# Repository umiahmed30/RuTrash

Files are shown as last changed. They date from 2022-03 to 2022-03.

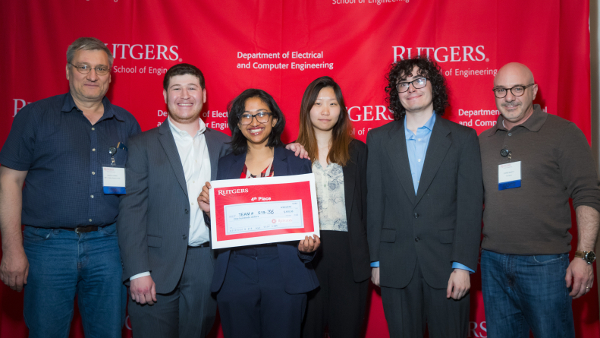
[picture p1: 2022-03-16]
4th-Place-2019_04_24_0681_RU_SOE_Capstone-600x338.jpg

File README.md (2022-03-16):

# RU Recycle
Fourth place winner of the Rutgers Capstone Expo 2019. Refer to the documents section for report, demo video, and poster.

Abstract:

America accumulates more than 254 million tons of trash annually, but recycles only 34.5% of its total municipal waste. Although most are aware of the consequences of pollution and landfills, many individuals fail to recycle accurately due to lack of access or inconvenience. Our team proposes a solution to this issue with a self sorting trash can. This device will use computer vision and various sensors to categorize a disposed item and send it to the appropriate bin using a conveyor belt mechanism. We will finetune the Resnet-50 neural network architecture with thousands of images of waste to categorize its findings into: paper, plastic, metal, glass, and trash. We will use a Raspberry Pi 3 B+ in conjunction with an Arduino Pro Micro to control the conveyor belt system. With our project, we aim to streamline the process of recycling with efficiency and accuracy.

Acknowledgements: 

Training Dataset obtained from Trashnet: https://github.com/garythung/trashnet

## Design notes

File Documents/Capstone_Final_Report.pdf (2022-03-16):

# RU Recycle: A Smart Self-Sorting Trash Can Using

# Deep Neural Network

Steven Coulter, Umama Amhed, Yiwen Zhou, Jake Rodin, Professor Sheng Wei

May 8, 2019

## Contents

1 Introduction | 4
2 methods | 6
3 Cost and Sustainability Analysis | 16
4 Conclusion | 18
5 Apendix | 18

6 Works Cited | 26

## 1 Introduction

In the US we produce a significant amount of waste but only recycle a small amount of it. According the

EPA, “In 2013, Americans generated about 254 million tons of trash and recycled and composted about

87 million tons of this material, equivalent to a 34.3 percent recycling rate. On average, we recycled and

composted 1.51 pounds of our individual waste generation of 4.40 pounds per person per day,” (EPA, 2016).

That 254 million tons of trash can be sorted by type of waste, shown in this plot.

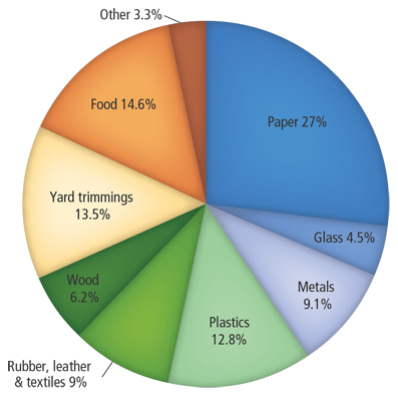
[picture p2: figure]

Figure 1: Percentage of Types of Waste Produced in 2013 (EPA,2016)

It clearly illustrates that the US disproportionally disposes of a lot of recyclable material as garbage. In

total 53.4 percent of our waste in 2013 was recyclable but we only recycled 34.3 percent of it. This disparity

is due to many factors, according to a 2016 article in the Huffington Post, The three major responses,

as illustrated in the plot below, on why people do not recycle in order from most to least common are:

people seeing recycling is inconvenient, it takes too much time and forgetfulness. These excuses have greatly

hindered our efforts to effectively recycle.

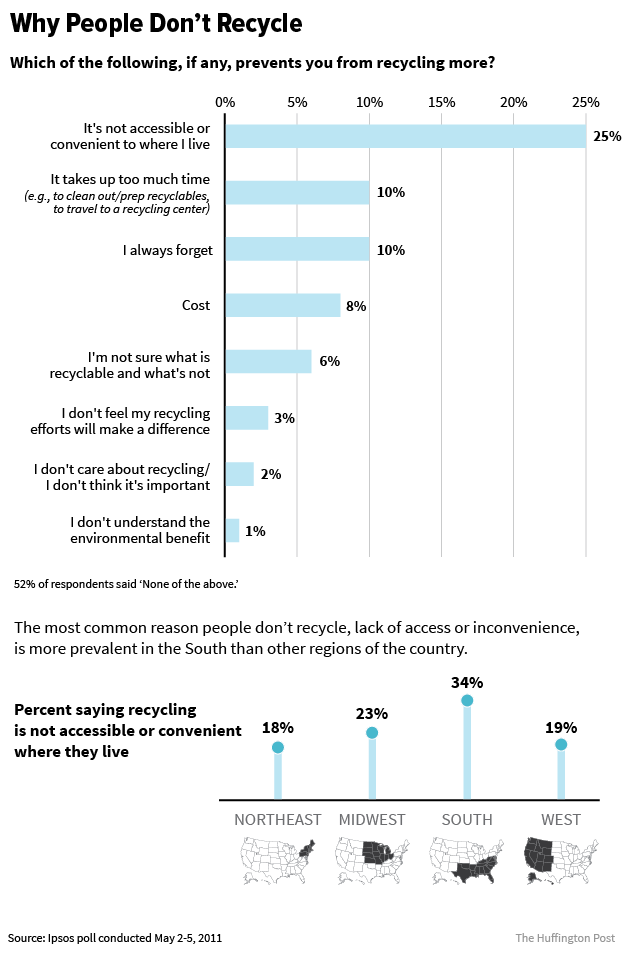
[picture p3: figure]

Figure 2: Responses to Why People Don’t Recycle (Schumaker, 2016)

In response to these problems of inconvenience, we created a self-sorting trash can. This solution would

make it easy for the user by decreasing time and eliminating the ”thought” that goes to sorting waste, as well

as cut down on the amount of menial labor required at recycling plants. This device will use deep learning

and various sensors to categorize the disposed item and send it to the appropriate bin using a conveyor belt

mechanism. The neural network we fine tuned uses thousands of images of waste to categorize its findings

into paper, plastic, metal, glass, and trash. We will use a Raspberry Pi 3 B+ in conjunction with an Arduino

Pro Micro to control a conveyor belt system. With our project, we aim to streamline the process of recycling

while maximizing efficiency and accuracy to a degree that other similar products do not.

An example of a similar product would be CleanRobotics’ TrashBot, which “utilizes a variety of sensors,

robotics and artificial intelligence (AI) in order to detect what a piece of waste is, classify it as recyclable or

not, then separate the item into the correct receptacle,” (Greenwalt, 2017). Our project intends to take it

a step further and sort the waste into five separate categories of paper, plastic, metal, glass, and trash. By

having all the waste sorted before it reaches the recycling plant, our project will help decrease the amount of

time, labor, and money expended by either users at home or recycling plants. This project will streamline

the process of recycling while also decreasing the amount of time money and effort needed to recycle.

## 2 methods

As mentioned before, our goal was to create a device that uses deep learning and various sensors to categorize

an item and send it to the appropriate bin through a conveyor belt mechanism. We used a variety of methods

in order to successfully implement our design. We tackled this project from two engineering aspects: hardware

and software.

### 2.1 Flowchart

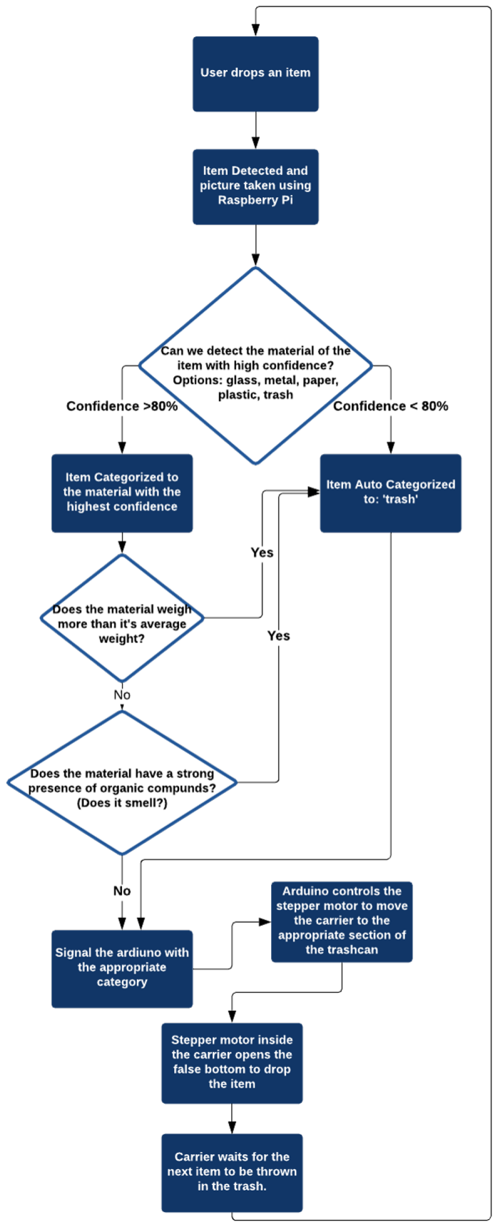
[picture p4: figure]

Figure 3: a flowchart detailing the project

### 2.2 Methods Used

### 2.2.1 Hardware

Before we started this project, we had to familiarize ourselves with some of the technologies we plan to use.

From a hardware perspective, we needed to know how to use stepper motors, limit switches, and general pcb

design. Some other skills that are required is a basic knowledge of soldering, constructing objects with power

tools, and operating a 3D printer, which allows for faster acquisition of parts at a low cost. Experience with

serial connections and C allowed for better use of the Arduino and bridging to the PI. Understanding and

use of a laser cutter was also a necessary skill in order to produce the parts necessary for the projects.

### 2.2.2 Software

From the software side, the following were our design goals:

1. Use an appropriate machine learning architecture to finetune with our dataset.
2. Find a dataset to train given our recycling categories.
3. Pick a programming language that allows for easy interface with the Raspberry Pi and allows for easy

use of neural network programming.

In addition, we had to be well acquainted with unix operating systems, crontab operations, and shell scripting

in order to save power and run our system efficiently.

### 2.3 Design Implementation and chalanges

### 2.3.1 Hardware

### 2.3.1.1 Design

The device operates on the principle of linear control through a stepper - belt mechanism and control through

an Arduino and Raspberry Pi mechanism. If the Raspberry Pi sends data to the Arduino, then the Arduino

will respond by controlling the steppers to move over the top of the correct trashcan segment and have a

servo drop the trash. The stepper will move back and forth to shake any excess trash off the platform. The platform will then reset and the carrier will move back to the home position. This creates a feedback loop

that is illustrated in the above flowchart.

### 2.3.1.2 Challenges

One of the largest challenges that we have encountered from the hardware perspective is the design constraint

of the physical trash can. As it stands we have currently solved this by merging two existing trash cans;

however ordering the chosen cans has proven difficult. Due to time constraints, we are forgoing creation of

a specialized control unit that is capable of both control of the can and image analysis, such a control unit

would be more effective in a large scale project however in the interest of the prototype, Thus in favor of both

time and money, we have chosen to use a two board system, consisting of a Raspberry Pi and an Arduino.

Overall we have not run into many regulatory issues, other than recycling standards and sorting codes.

However, we expect the nuances of recycling code impede us in the future. Additionally, conventional trash

cans available in stores are not large enough to house five types of trash in a realistic situation. Solution:

merge two trash cans together to give more room to each compartment. The synchronization of the stepper

motors caused a big challenge in the hardware side. In order to make them turn in sync, they had to be

driven from the same Arduino pin. This caused issues, as one stepper driver originally did not use as much

current as the other, causing issues in the feed torque and forcing the carrier to have a torque along the rods.

Solution: tune the current output of the steppers using a multimeter.

### 2.3.2 Software

### 2.3.2.1 Design

From the software side, we wrote two python scripts to train and test our machine learning architecture and

one final script to detect objects with machine learning and the sensors combine. Once an item is thrown into

our device, we take a picture using Raspberry Pi camera and calculate the sorting category using the test

code. If we can not determine a suitable category with at least 70% confidence, we will auto assign the item

to the ‘trash’ category. Due to the fact that a wide variety of items can be thrown in trash, sometimes it can

be challenging even for humans to decide if an item can be recycled or not. To avoid cross contamination,

we do not want to throw things into one of the recycling categories unless we are absolutely confident of the

resulting category. Furthermore, we had to find a database of images of trash that suited our needs. From

our research online, we found the Trashnet, which was the most complete open source database that included

variety of pictures from all our categories. We obtained permission from the creators before continuing on with our project. We had to modified the database a little to include cardboard into paper category. “The

pictures were taken by placing the object on a white poster board and using sunlight and/or room lighting.

The pictures have been resized down to 512 x 384, which can be changed in data/constants.py (resizing them

involves going through step 1 in usage). The devices used were Apple iPhone 7 Plus, Apple iPhone 5S, and

Apple iPhone SE” (Thung, 2017).

### 2.3.2.2 Code Layout

In the following paragraphs, we will describe how we fine-tune our architecture to detect our recycling

categories. We have chosen to work with ResNet50. While there are a lot of CNNs out there, a problem

with directly mapped networks was that the deeper the networks were, the accuracy saturated and degraded

more rapidly. ResNet uses network layers to fit a desired underlying mapping. It is easy for a residual block

to learn an identity function, thus it allows us to add more and more layers to our training blocks without

degrading quality of increasing training error (Jay, 2018). ResNet also uses a lot of the same convolutions so

the dimensions between layers stay consistent. ResNet50 is a 50-layer Residual Network but there are other

variants like ResNet101 and ResNet152 also. Below is an example of a residual block of ResNet: Below we

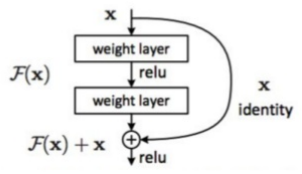
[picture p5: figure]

Figure 4: Residual block (Jay,2018)

will highlight the step-by-step process to fine tuning:

1. Preprocessing: keras includes a built-in image data generator which generates batches of image data

with real time data augmentation looped over in batches. This is executed to suppress unwanted dis-

tortions or enhance some image features important for the next level. We use the flow from directory()

function to specify our training directory. We set our class mode to categorical to categorize the 5

classes, set shuffle to true to randomize our images, and set our batch size to 16. Batch size defines the number of samples propagated through the network: typically networks train faster in mini batches so

we have chosen the value to be 16.

2. Fine-tuning Layers: After loading up ResNet 50, we have chosen to truncate the last layer with

model.layers.pop(). Since we are only classifying 5 categories, we are replacing the layer with our own

softmax layer so instead of the 1000 categories of imagenet, the new layer will only look at 5. From

research we have found that it is common practice to freeze the previous layers of the pre-trained

network. The initial layers extract universal features like curves and edges that are still relevant to the

new classes, so we have chosen to not modify them. Another parameter to define here is the learning

rate: it is simply the rate at which the network abandons old weights for new ones. we chose a very

small learning rate of 0.0001, since the pre-trained weights are already pretty good, we don’t want to

distort them too much.

3. Model Fitting: we use the keras function fit generator() to start the fine-tuning process. The number

of training steps is specified to be training samples/batch size. We use a total of 2500 pictures to train

our 5 classes and 30 images per category to validate. The term epoch refers to the number of times the

entire dataset is passed forward and backward through the neural network. As the number of epoch

increases, the number of times the weight changes increases as well. Now this could be a good thing

and a bad thing: the good news is more epoch will result in underfitting whereas too many epochs

can cause overfitting. The term overfitting means a network will be so good at recognizing your own

dataset that it won’t be able to recognize new images with slightly different parameters. Underfitting

will give us a network that is too generalized to accurately recognize any images. To solve this issue

we will use a method called early stopping.

Figure 5: Early Stopping function

Setting the patience to 10, we have basically setup a checkpoint to test if the loss has improved in the last

10 epoch. We set up save best only to true to save the best model after each checkpoint.

### 2.3.2.3 Challenges

Due to the fact that a wide variety of items can be thrown in trash, it can be challenging even for humans

to decide if an item can be recycled or not. For example, containers with food/liquid still inside should

not be recycled in order to avoid cross contamination. Solution: Add weight sensor and Volatile Organic

Compound (VOC) sensor to the carrier. These sensors will help determine if food particle/excess liquid is

still inside a container. For example, if a plastic bottle is thrown into our device with liquid still inside, we

would be able to use the weight sensor to determine that the object weighs more than an average plastic

bottle, hence it belongs to trash. Additionally, if a greasy napkin is thrown into the device, we would be

able to use the VOC sensor to detect the food particles and send the item to trash.

### 2.4 Tools used:

- Android Studio
- Oracle VM Virtual Machine on our windows 10 to use Ubuntu (64 bit)
- Python 2.7
- ResNet50
- trashnet
- Laser Cutter
- arduino IDE
- EasyTerm.

### 2.5 Limitations

### 2.5.1 Hardware

A Raspberry Pi is not quite fast enough for simultaneous use of the neural network and drive stepper motors.

Secondarily, we have run into the issue of availability of some parts, namely the trashcans and the steel rods.

However most of the technology we need is consumer grade technology and off the shelf CNC hardware, so

it was easily implimented.

### 2.5.2 Software

We only have about 2500 images from trashnet, which is enough for now but will not be enough if this device

was used at a large scale. So what we plan to do is continue to grow the database by uploading the picture of any trash that we come across in our device, then once we have x amount of pictures, we will retrain our

architecture.

### 2.6 Use of Standards

- IEEE 802.11 - Wifi, our project will employ wifi in order to communicate data back to our main servers.
- RS-232 - in order to enable communication between the Raspberry Pi and Arduino use of serial com-

munication is required.

- RESNET50 - See Above paragraph on use of neural net
- Python 2.7 - Used to facilitate resnet50
- Tensorflow: Used to facilitate resnet50
- IEEE 1666-2005 - C standard library package, useful for arduino, 2005 version still relevant though

newer versions available

- IEEE Standard 1003.1 - Bash standard, useful to limit power consumption on the pi because running

the whole python script (having the entire neural network in ram at all times) would consume a lot of

power.

### 2.7 Experiment/Product results

### 2.7.1 Hardware

The system functioned as intended. The hardware was able to move to the correct due to application of

method of successive approximations. Below are some pictures of the functional hardware.

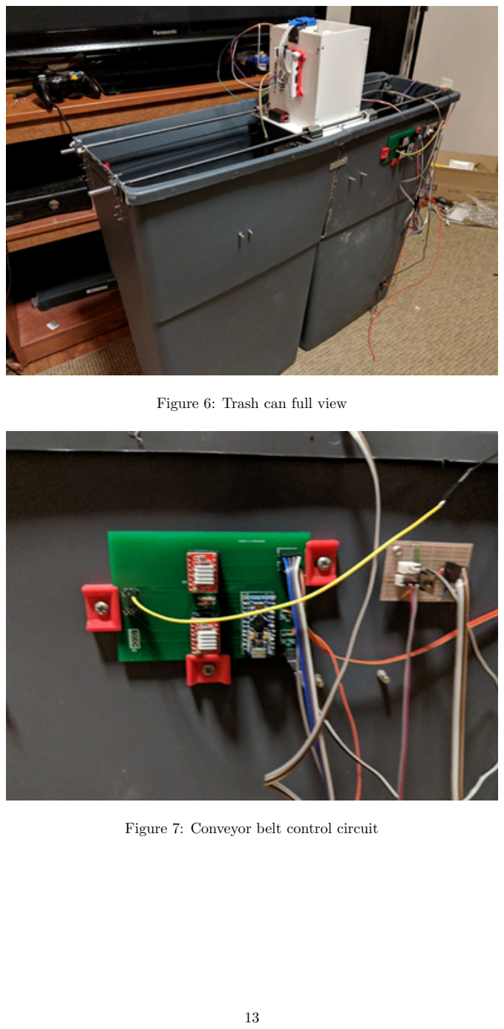
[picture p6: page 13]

Figure 6: Trash can full view

Figure 7: Conveyor belt control circuit

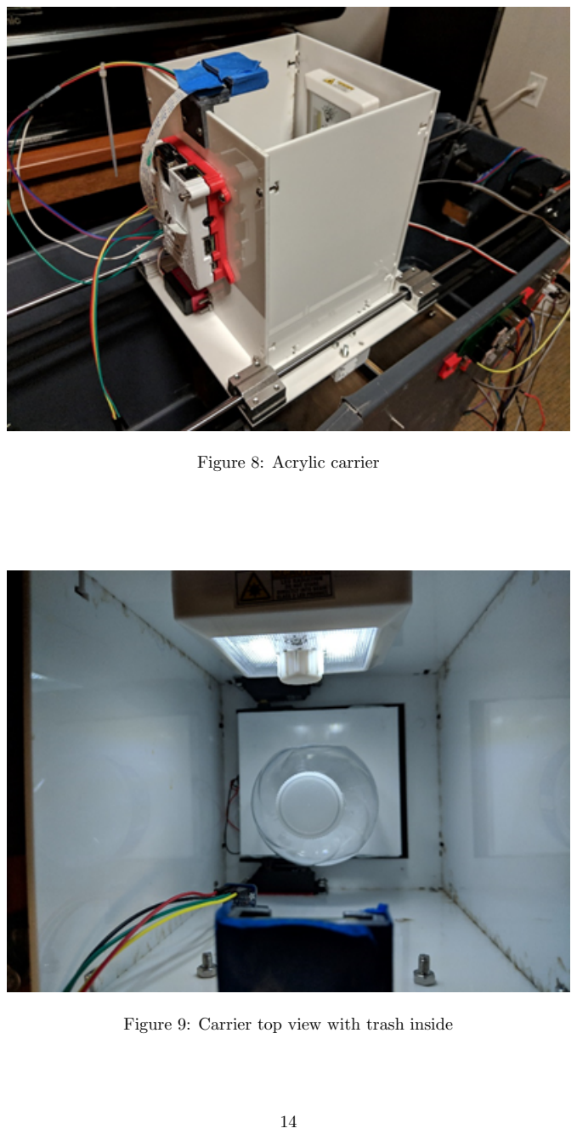
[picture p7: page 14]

Figure 8: Acrylic carrier

Figure 9: Carrier top view with trash inside

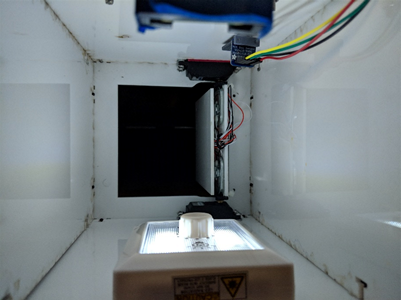
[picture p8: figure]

Figure 10: Carrier top view with false bottom open

### 2.7.2 Software

After training against the trashnet, I used 30 pictures of each category using the Raspberry Pi camera to

test my prediction algorithm. I used sklearn to collect the accuracy, precision, recall, f-score to create my

classification report. I also collected the accuracy of my prediction algorithm as seen below:

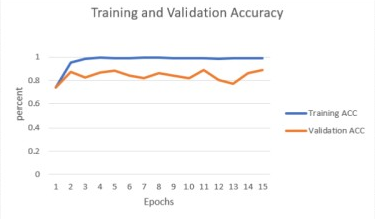
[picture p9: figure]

Figure 11: Training and Validation Accuracy vs the number of epochs

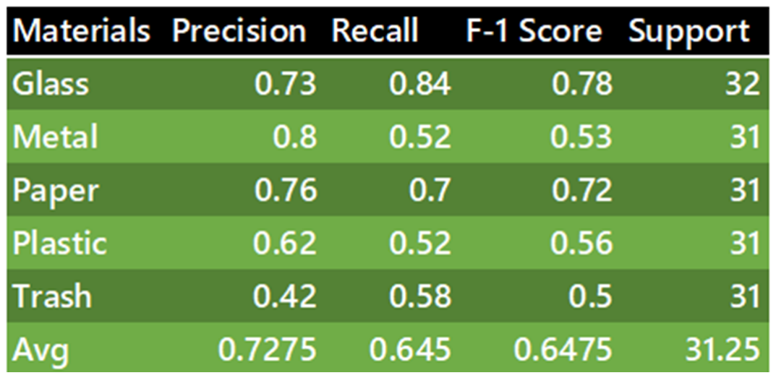
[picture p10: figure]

Figure 12: Classification Report

As observed, glass, metal and paper was accurately validated over 70% of the times. Plastic was

validated 62% of the time. Trash generated the worst result with 42% precision. The reason for precision

of trash being significantly lower than the others is because the category itself is very diverse. Many things

can be categorized as trash: some that may seem like they belong in one of the other categories at first

glance. Therefore, we used the VOC sensor and weight sensor to decrease our errors. With more pictures

of disposable items and a processing unit and camera more powerful than those provided by the Raspberry

Pi, we would be able to increase our accuracy even more.

## 3 Cost and Sustainability Analysis

### 3.1 Economics (cost) impact

Our prototype costs $277.96. However, the price can be greatly reduced if we were to move our product into

mass production. Buying items, such as metal rods, kevlar belts, and cables, in bulk would greatly reduce

the cost for each individual bin. Currently, we are modifying premade trash cans to our specific design;

although, if we were to employ a factory to make bins with our specific dimensions in large quantities, it

would again greatly reduce the price and time to produce our product. The majority of costs for our electrical

components can also be cut if we were to mass produce specific components for our trash can. This product

is also energy efficient. When the trash can is not sorting, it turns off, so it does not draw power when it

is not needed. According to a study from 2001 released by CalRecycle (formerly the California Integrated

Waste Management Board), recycling one ton of waste would be equal to a pay increase of “$101 in salaries

and wages, produce $275 more in goods and services, and generate $135 more in sales than disposing of it in a landfill” (Morrigan, 32). Using these numbers, if half of the recyclables and compostables from the west

coast (California, Oregon, and Washington) reported in this study were recycled, then the result would be

“almost a $1.6 billion increase in additional salaries and wages, $818 million increase in additional goods and

services produced, and $309 million increase in additional sales” (Morrigan, 32). These numbers would also

translate to increased revenue for each state, especially through income, property, and sales taxes (Morrigan,

32). Of course, if we calculated this on a national number, the numbers would be even bigger. In fact, the

EPA (Environmental Protection Agency) has done these calculations in an update to the national Recycling

Economic Information (REI) Study in 2016. The study found that a single year of recycling in the United

States accounted for 757,000 jobs, $36.6 billion in wages, and $6.7 billion in tax revenues (“Recycling Basics”,

2018).

### 3.2 Environmental impact of the product

Our autonomous sorting trash should provide a positive impact to the environment. The average US citizen

discards 7.5 pounds of solid waste a day (“Frequently Asked Questions: Benefits of Recycling”, 2019). By

removing recyclables from the solid waste stream, we save a lot of space in landfills, preventing them from

overflowing too quickly. Recycling also slows down our consumption of natural resources like wood and

water, prevent pollution because we are reducing the need to collect raw materials, and save the energy

needed to manufacture new products (“Benefits of Recycling,” 2019). For example, recycled aluminum saves

95% production energy, recycled steel 60%, recycled newspapers 40%, recycled plastics 70%, and recycled

glass 40% (“Benefits of Recycling,” 2019). In 2010, to meet the growing paper consumption demands, 80%

more wood would need to be harvested in comparison to only 20% more wood needed if people were actively

recycling paper (“Benefits of Recycling,” 2019). Recycling reduces greenhouse gas emissions too (“National

Overview: Facts and Figures on Materials, Wastes and Recycling”, 2018).

### 3.3 Social impact of the product

Our product will make recycling less labor intensive and more convenient for the average consumer. It will

cut down the time and energy needed for everybody to recycle and the need for manual recycling in single

stream recycling facilities. It also reduces the need for landfills, which would make towns prettier and less

smelly on days where the wind blows in the wrong direction.

## 4 Conclusion

Our goal for this project was to make the process of recycling more accurate and efficient at the bin level.

We were able to do so by creating a device that sorts and disposes of items thrown with high accuracy. We

fine tuned the Resnet-50 neural network architecture with thousands of images of waste to categorize its

findings into: paper, plastic, metal, glass, and trash. We used a Raspberry Pi 3 B+ in conjunction with an

Arduino Pro Micro to control the conveyor belt system. We were able to achieve a precision score of 72%

on average among the 5 categories. Trash being a complex category, achieved the lowest precision score, so

we improved our results by adding a VOC sensor and a weight sensor to detect leftover food in the disposed

item. In the future, we would like to use a more powerful processing unit than Raspberry pi to decrease

operation time at the software level. We want to collect more pictures of disposable items to improve our

fine tuning architecture. From the hardware side, we would like to build a bigger acrylic carrier to allow for

larger items to be disposed. Additionally, we plan to experimentally determine the location of the bins and

rotation of the belts to eliminate any possibility of dropping an item in the wrong section of the trash can.

## 5 Apendix

Attached below is our code for the project:

### 5.1 predict.py

the live runnable for our code demo On the raspberry Pi

import json , os , re , sys
import numpy as np
from keras import backend as K
from keras.models import load model from keras. preprocessing import image from picamera import PiCamera
from time import sleep
from PIL import Image
import serial
import board
import busio
import adafruit sgp30
import time

#I n i t i a t e weight sensor

EMULATE HX711 =False
if not EMULATE HX711 :

import RPi.GPIO as GPIO
from hx711 import HX711
else:
from emulated hx711 import HX711

def cleanAndExit ():
print ("Cleaning...")

if not EMULATE HX711 :
GPIO.cleanup ()

print ("Bye!")
sys.exit ()

hx = HX711 (5, 6)

if | n a m e | == ’ | m a i n | ’:
model path = sys.argv [1]

print (’Loading serial’)
for x in range(10):
name = ’/dev/ttyACM’ + str(x)
| try:
ser = serial.Serial(name)
except:
continue

print(ser.name)

print(’Loading model:’, model path ) model = load model ( model path ) image2 = ’image2.jpg’
| run= ’y’

voc = True
weight sensor = True

# Setup i2c

print(’Setting up i2c...’) try:
thres smell = 0
min smell = 0
max smell = 0
smell = []
i2c = busio.I2C(board.SCL , board.SDA , frequency =100000) sgp30 = adafruit sgp30 . Adafruit SGP30 (i2c)
sgp30. iaq init ()
sgp30. set iaq baseline (0x8973 , 0x8aae)
for i in range(40):
print("eCO2 = %d ppm \t TVOC = %d ppb" % (sgp30.eCO2 , sgp30.TVOC))

sleep (1)
except:
print ("VOC failed")

voc = False

# Setup weight sensor

print(’Setting up weight sensor...’) try:
hx. set reading format ("MSB", "MSB") hx. set reference unit (4.09) hx.reset ()
hx.tare (50)
offset prev = hx.tare (50) except:
print ("weight sensor failed") weight sensor = False
print ("Place object now...")

while(run ==’y’):
thres smell = 0
camera = PiCamera ()
camera. start preview ()
sleep (10)
camera.capture(image2)
camera. stop preview ()

if voc:
smell = []
for i in range(20):
eCO2 = sgp30.eCO2
TVOC = sgp30.TVOC
print("eCO2 = %d ppm \t TVOC = %d ppb" % (eCO2 , TVOC))

smell.append(TVOC)
sleep (0.25)
smell = np.array(smell)
b = smell[::−1]
max smell = len(b) − np.argmax(b) − 1 if ( max smell == 0 ):
thres smell = 0
min smell = max smell
else:
min smell = np.argmin(smell [0: max smell ])
thres smell = smell[ max smell ] − smell[ min smell ] print("max", smell[ max smell ], "min", smell[ min smell ])

imageCrop = Image.open(image2)
cropped = imageCrop .crop ((570 ,105 ,1365 ,830))
save = cropped.save(’imageC.jpg’)
img2 = image. load img (’imageC.jpg’, target size =(224 , 224)) y = image. img to array (img2)

hx. set offset A ( offset prev )
y = np. expand dims (y, axis =0)
preds = model.predict(y)
print(preds)
print(’Generating predictions on image:’, image2)

category = 4
for p in range(4):
if (preds [0][p] >= 0.60): category = p

target names = [b’glass\n’,b’metal\n’,b’paper\n’,b’plastic\n’,b’trash\n’] print(’Predicted Category: ’)
print( target names [category ])
print(’After VOC test’)
if ( thres smell >= 20) and voc: category = 4
print(’VOC smelled food’)
print( target names [category ])

weight = np.zeros (10)
for w in range(10):
weight[w] = hx. get weight (1)
med weight = np.median(weight) print("Weight (in grams) =", med weight )
if (category == 1 or category == 3): print(’After food weight test’)
if ( med weight >= 200) and weight sensor : category = 4
print( target names [category ])
ser.write( target names [category ])

run = input(’would you like to continue? y/n’) camera.close ()
offset prev = hx.tare (50)
sleep (5)
ser.close ()

### 5.2 train.py

Training code for the computer vision system.

import math , json , os , sys

import keras
from keras. callbacks import EarlyStopping , ModelCheckpoint from keras.layers import Dense , AveragePooling2D
from keras.layers import Flatten
from keras.models import Model
from keras. optimizers import Adam
from keras. preprocessing import image import numpy as np
import sys
import scipy
from scipy import signal
from keras. applications .resnet50 import ResNet50 from keras. preprocessing import image
from keras. applications .resnet50 import preprocess input , decode predictions from sklearn.metrics import confusion matrix
from sklearn.metrics import accuracy score
from sklearn.metrics import precision score
from sklearn.metrics import recall score from sklearn.metrics import f1 score import matplotlib .pyplot as plt
import warnings

DATA DIR = ’data’
TRAIN DIR = os.path.join( DATA DIR , ’train’) VALID DIR = os.path.join( DATA DIR , ’valid’) SIZE = (224 , 224)
BATCH SIZE = 16
if | n a m e | == " | m a i n | ":

num train samples = sum([len(files) for r, d, files in os.walk( TRAIN DIR )]) num valid samples = sum([len(files) for r, d, files in os.walk( VALID DIR )])

num train steps = math.floor( num train samples / BATCH SIZE )
num valid steps = math.floor( num valid samples / BATCH SIZE )

gen = keras. preprocessing .image. ImageDataGenerator ( rotation range = 45, horizontal flip =True , vertical flip =True)
val gen = keras. preprocessing .image. ImageDataGenerator ( horizontal flip =True , vertical flip =True)

batches = gen. flow from directory ( TRAIN DIR , target size =SIZE , class mode =’ categorical’, shuffle=True , batch size = BATCH SIZE )
val batches = val gen . flow from directory ( VALID DIR , target size =SIZE , class mode = ’categorical’, shuffle=True , batch size = BATCH SIZE )
input size = 224
input channels = 3

classes = list(iter(batches. class indices ))
base model = ResNet50 ( include top = False ,weights="imagenet", input shape =( input size , input size , input channels ))
x = AveragePooling2D ((7 ,7) ,name=’avg pool ’)( base model .output)
x = Flatten ()(x)
x = Dense(len(classes),activation ="softmax")(x)
finetuned model = Model( base model .input ,x)
for layer in base model .layers:
layer. trainable = False
finetuned model . save weights ("all nontrainable50.h5")

base model = ResNet50 ( include top = False ,weights="imagenet", input shape =( input size , input size , input channels ))
x = AveragePooling2D ((7 ,7) ,name=’avg pool ’)( base model .output)

x = Flatten ()(x)
x = Dense(len(classes),activation ="softmax")(x)

finetuned model = Model( base model .input ,x)

for layer in base model .layers [:10]:
layer. trainable = False
finetuned model . load weights ("all nontrainable50.h5")

finetuned model .compile( optimizer =Adam(lr =0.001) , loss=’categorical crossentropy’, metrics =[’accuracy’])
for c in batches. class indices :
classes[batches. class indices [c]] = c
finetuned model .classes = classes

early stopping = EarlyStopping (monitor=’val loss ’,patience =10)
checkpointer = ModelCheckpoint (’resnet50 best train epoch 50 .h5’, verbose =1, save best only =True)

history = finetuned model . fit generator (batches , steps per epoch = num train steps , epochs =50, callbacks =[ early stopping , checkpointer ], validation data =
val batches , validation steps = num valid steps )
finetuned model .save(’resnet50 train epoch 50.h5’)
acc = history.history[’acc’]
val acc = history.history[’val acc ’]
loss = history.history[’loss’]
val loss = history.history[’val loss ’] print(acc)
print(loss)
print( val acc )
print( val loss )
ep = range(len(acc))
plt.plot(ep , val loss ,’b’,label = ’Valid loss’) plt.plot(ep ,loss ,’r’,label=’Training loss’) plt.plot(’T and V Loss’)
plt.legend ()
plt.show ()

Code running on the arduino to preform the motor control operations.

### 5.3 arduinocode.ino

#define dir 7

#define sw1 8 // MUST BE PULLED HIGH FOR SWITCHES to work #define sw2 9

#define en A1

#define stepp A0

#define servo A2

#include <Servo.h>

Servo myservo;
const int stepsPermm = 10; // change t h i s to f i t the number o f s teps per revolu t ion

int currentpos = 0;
String incoming = "";
// for your motor

// i n i t i a l i z e the s tepper l i b r a ry on pins 8 through 11:
enum input {glass , paper , plastic , metal , trash , bad}; input readin (String const& inString) {
if (inString == "glass\n") return glass;
if (inString == "paper\n") return paper;
if (inString == "plastic\n") return plastic; if (inString == "metal\n") return metal;
if (inString == "trash\n") return trash; return bad;
}

void moveto (int pos) {

digitalWrite (en , LOW);
digitalWrite (dir , LOW);
digitalWrite (stepp , LOW);
int stepon = 0;
while ( digitalRead (sw2) == HIGH) { if (stepon == 0) {

stepon = 1;
digitalWrite (stepp , LOW); delay (2);
} else {

stepon = 0;
digitalWrite (stepp , HIGH); delay (2);
}

}

delay (100);
digitalWrite (dir , HIGH);
for (int x = 0; x < pos ∗ stepsPermm ; x++) { if (stepon == 0) {

stepon = 1;
digitalWrite (stepp , LOW);
delay (2);
} else {

stepon = 0;
digitalWrite (stepp , HIGH); delay (2);
}
}
for(int x = 10; x <= 120; x++){

myservo.write(x);
delay (15);
}

delay (3000);
for(int x = 120; x >= 10; x−−){

myservo.write(x);
delay (15);
}

delay (1500);
digitalWrite (dir , LOW);
while ( digitalRead (sw2) == HIGH) { if (stepon == 0) {

stepon = 1;
digitalWrite (stepp , LOW);
delay (2);
} else {

stepon = 0;
digitalWrite (stepp , HIGH); delay (2);
}

}

digitalWrite (en , HIGH);
Serial.println("Ok");
}
void setup () {

pinMode(sw1 , OUTPUT);
pinMode(sw2 , INPUT);
pinMode(dir , OUTPUT);
pinMode(en , OUTPUT);
pinMode(stepp , OUTPUT);
myservo.attach(servo);
Serial.begin (9600);
}

void loop () {

digitalWrite (sw1 , HIGH);
digitalWrite (en , HIGH);
incoming = "";
// s tep one revolu t ion in one d irec t ion :
if (Serial. available () > 0) {
// read the incoming by te :

incoming = Serial. readString ();
switch (readin(incoming)) {
case metal:
Serial.println("movining to metal"); moveto (0); // for s a f tey
break;
case paper:
Serial.println("movining to paper"); moveto (130);
break;
case glass:
Serial.println("movining to glass"); moveto (250);
break;
case plastic:
Serial.println("movining to plastic"); moveto (415);
break;
case trash:

Serial.println("movining to trash"); moveto (600);
break;
default:
break;
}
}
}

## 6 Works Cited

(n.d.). Retrieved from https://www.gnu.org/software/bash/manual/htmlnode/W hat − is − Bash003f.html

1666-2005 - IEEE Standard SystemC(R) Language Reference Manual. (2006, March 31). Retrieved from https://ieeexplore.ieee.org/document/1617814

Benefits of Recycling. (n.d.). Retrieved from https://nems.nih.gov/environmental-programs/Pages/Benefits-of-Recycling.aspx

Frequently Asked Questions: Benefits of Recycling. (n.d.). Retrieved from https://lbre.stanford.edu/pssistanford-recycling/frequently-asked-questions/frequently-asked-questions-benefits-recycling Greenwalt, M. (2017, July
27). | One Pittsburgh-based Tech Company Has Developed a Self-Sorting Trash Bin. | Retrieved from
https://www.waste360.com/fleets-technology/one-pittsburgh-based-tech-company-has-developed-self-sorting-trash-bin

Jay, P., Jay, P. (2018, February 07). Understanding and Implementing Architectures of ResNet and ResNeXt for state-of-the-art Image... Retrieved from https://medium.com/@14prakash/understanding-and-implementing-architectures-of-resnet-and-resnext-for-state-of-the-art-image-cf51669e1624

Morrigan, M., Smith, B., Davis, J. (2011). Reducing Greenhouse Gas Emissions through Recycling and Com-posting in California, Oregon, and Washington. The Evans School Review, 1(1), 23-35. Retrieved February 10, 2019, from https://depts.washington.edu/esreview/wordpress/wp-content/uploads/2012/12/ESR-2011-Research-Reducing-Greenhouse-Gas-Emissions-Through-Recycling-and-Composting.pdf

Municipal Solid Waste. (2016, March 29). Retrieved from https://archive.epa.gov/epawaste/nonhaz/municipal/web/html/

National Overview: Facts and Figures on Materials, Wastes and Recycling. (2018, October 26). Retrieved from https://www.epa.gov/facts-and-figures-about-materials-waste-and-recycling/national-overview-facts-and-figures-materialsGenerationTrends

Recycling Basics. (2018, August 01). Retrieved from https://www.epa.gov/recycle/recycling-basics

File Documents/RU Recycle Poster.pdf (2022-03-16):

☐ ResNet-50 finetuned with TrashNet [1] consisting of 2527 images:
- ResNet uses network layers to fit a desired underlying mapping. Because identity function is easy for a residual block to learn, it allows the user to add more and more layers to the training blocks without degrading quality or increasing training error. [4]

## Umama Ahmed, Steven Coulter, Jake Rodin, Yiwen Zhou {ua66, sbc93, jar492, yz564}@scarletmail.rutgers.edu Advisor: Prof. Sheng Wei

## Introduction

America accumulates more than 254 million tons of trash annually, but recycles only 34.5% of its total municipal waste. Although most are aware of the consequences of pollution and landfills, many individuals fail to recycle accurately due to lack of access or inconvenience. We aim to streamline the process of recycling with efficiency and accuracy with a self sorting trash can.

Hardware Methodology | Software Methodology

## Results

## References

[1] Gary Thung Mindy Yang. “Classification of trash for recyclability status”. CS229 Project Report 2016, 2016. [Online] Available: https://github.com/garythung/trashnet. [Accessed: Apr. 18,2019].
[2] Recyclebank, “Why Can’t I Recycle Stuff with Food On It”, Recyclebank, Sept. 10,2014. [Online] Available: https://livegreen.recyclebank.com/column/because-you-asked/why-can-t-i-recycle-stuff-with-food-on-it. [Accessed: Apr. 18,2019].
[3] Jason Brownlee, “A Gentle Introduction to Learning Curves for Diagnosing Machine Learning Model Performance”, Machine Learning Mastery, Feb. 27, 2019. [Online] Available: https://machinelearningmastery.com/learning-curves-for-diagnosing-machinelearning-model-performance/. [Accessed: Apr. 18,2019].
[4] Prakash jay, ”Understanding and Implementing Architectures of ResNet and ResNeXt for state-of-the-art Image Classification: From Microsoft to Facebook “, Medium, Feb. 7, 2018. [Online] Available: https://medium.com/@14prakash/understanding-andimplementing-architectures-of-resnet-and-resnext-for-state-of-the-art-image-cf51669e1624. [Accessed: Apr 19,2018]

## Acknowledgement

We would like to thank Professor Sheng Wei for guiding us and providing valuable insight throughout the project. We would like the Livingston Apartment Maintenance Crew for speaking to us about the importance of recycling accurately. We would like to thank our friends from various departments for their constant support. We would also like to thank The ECE department for providing us with the necessary resources to complete our project.

# RU Recycle: A Smart Self-Sorting Trash Can Using Deep Neural Network

## Research Challenges

Software Challenges:

☐ Due to the fact that a wide variety of items can be thrown in trash, sometimes it can be challenging even for humans to decide if an item can be recycled or not. For example, containers with food/liquid still inside should not be recycled in order to avoid cross contamination [2].
- Solution: Add weight sensor and Volatile Organic Compound (VOC) sensor to the carrier. These sensors will help determine if food particle/excess liquid is still inside a container.

Hardware Challenges:

☐ Conventional trashcans available in stores are not large enough to five types of trash in a realistic situation.
- Solution: merge two trashcans together to give more room to each compartment.

☐ The synchronization of the stepper motors caused a big challenge in the hardware side: in order to make them turn in sync they had to be driven from the same Arduino pin. This caused issues, as one stepper driver originally did not use as much current as the other, causing issues in the feed torque and forcing the carrier to get turned along the rods.
- Solution: tune the current output of the steppers using a multimeter.

## Goals

Design and build a device that will use computer vision and various sensors to categorize a disposed item and send it to the appropriate bin using a conveyor belt mechanism.

- Finetune the ResNet-50 neural network architecture with thousands of images of waste to categorize its findings into: paper, plastic, metal, glass, and trash.
- Use a Raspberry Pi 3 B+ in conjunction with an Arduino Pro Micro to control the conveyor belt system which will transport and drop the waste into the correct bin as identified by the neural network.

## Future Work

☐ Use a more powerful processing unit than Raspberry pi to decrease operation time at the software level.
☐ Build a bigger acrylic carrier to allow for larger items to be disposed.

## Technologies Used

Figure 1: Solidworks design of trash can with the carrier attached on two linear rods

Figure 2: EasyEDA design of the PCB circuit board which communicates with the Raspberry Pi to control the stepper motor

Figure 3: Flowchart of the entire process

Figure 4: ResNet-50 architecture

Figure 6: Example pictures of every category from the training database from left to right: paper, metal, trash, glass, plastic

Figure 5: Code snippets
from the training function.

Figure 7e: Carrier
top view with false
bottom open

Figure 8: Precision, recall, f1-score, and support (number of data per class) of validation data of each category [3]

Figure 7d: Carrier
top view with
trash inside
Figure 7a: Trash can full view | Figure 7b: Conveyor belt control circuit | Figure 7c: Acrylic carrier

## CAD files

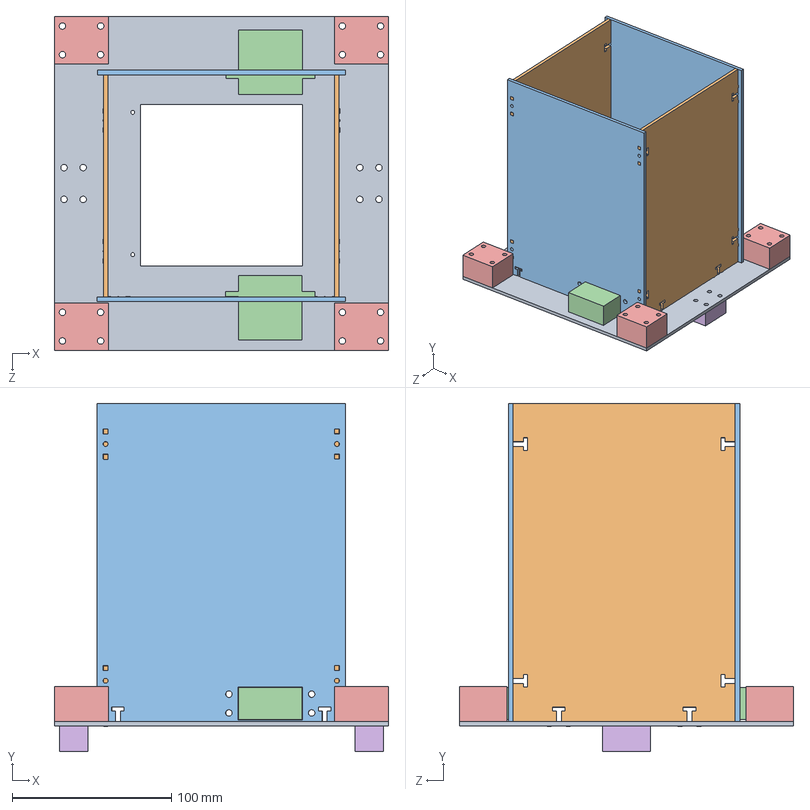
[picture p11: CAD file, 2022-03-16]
Documents/3D Printed Hardware Part Designs/Acrylic Carrier/carrier full.SLDASM
210.0 x 219.0 x 210.0 mm
carrier bottom
capstone wall length x 2
capstone wall width x 2
cheap servo x 2
scs 8 uu bearing x 4
belt holder x 2

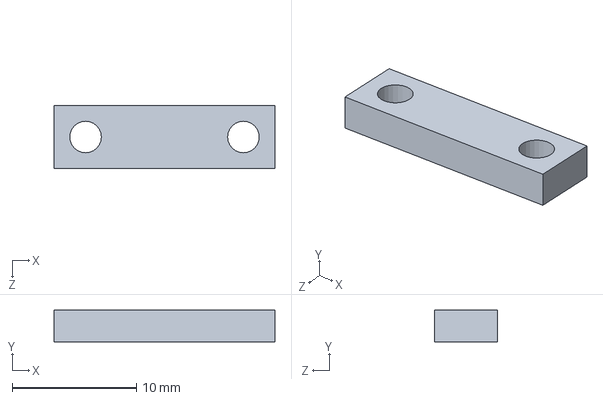
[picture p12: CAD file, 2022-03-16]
Documents/3D Printed Hardware Part Designs/voc lid.SLDPRT
17.8 x 2.54 x 5.08 mm

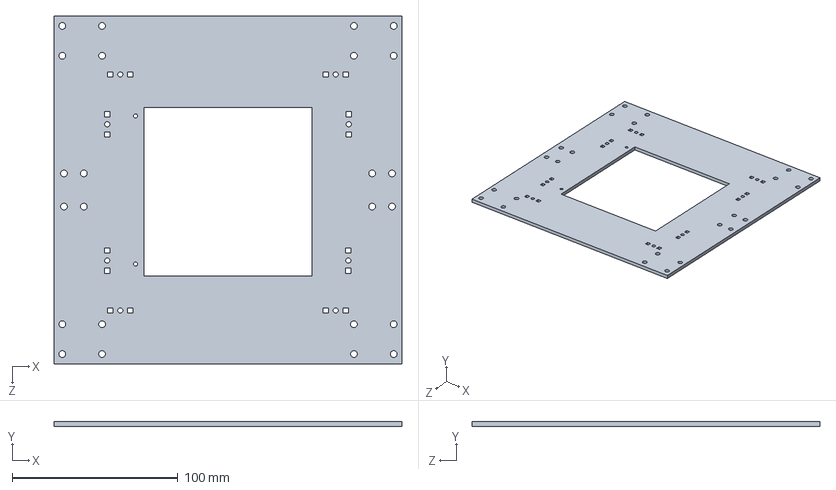
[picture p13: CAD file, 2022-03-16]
Documents/3D Printed Hardware Part Designs/Acrylic Carrier/carrier bottom.SLDPRT
210.0 x 3.00 x 210.0 mm

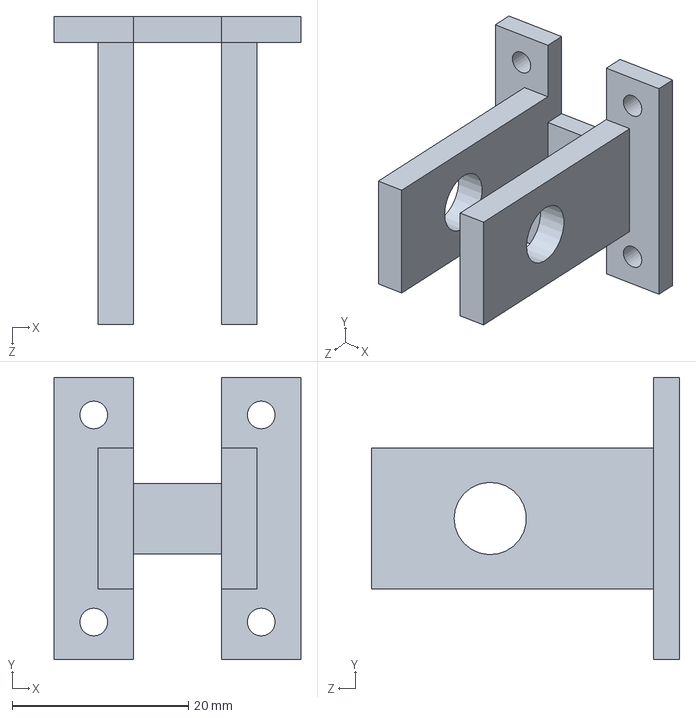
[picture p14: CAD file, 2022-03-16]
Documents/3D Printed Hardware Part Designs/skate board bearing mount.SLDPRT
28.0 x 32.0 x 35.0 mm

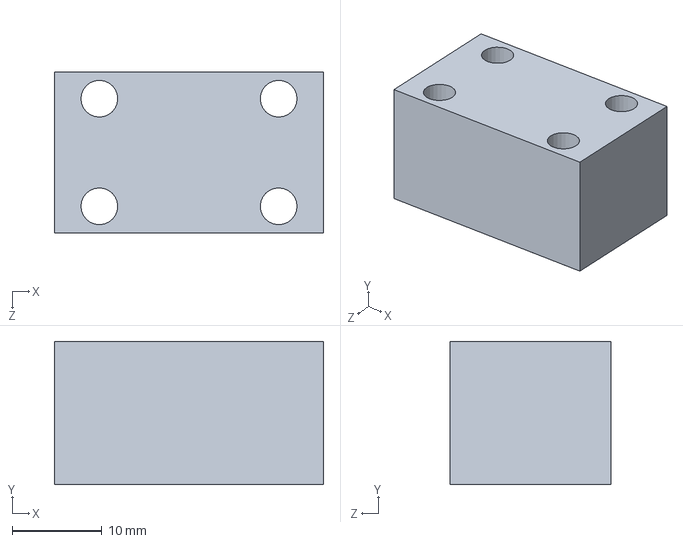
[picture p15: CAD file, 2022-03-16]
Documents/3D Printed Hardware Part Designs/Acrylic Carrier/belt holder.SLDPRT
30.0 x 16.0 x 18.0 mm

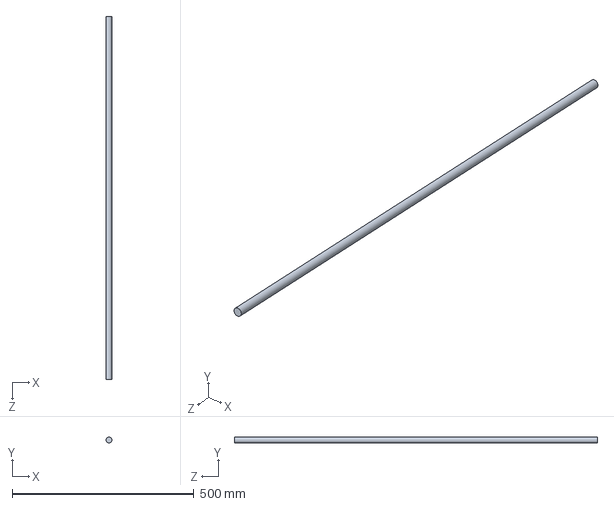
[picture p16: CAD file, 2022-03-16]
Documents/3D Printed Hardware Part Designs/capstone 8 x 1000 mm rod.SLDPRT
16.0 x 16.0 x 1000.0 mm

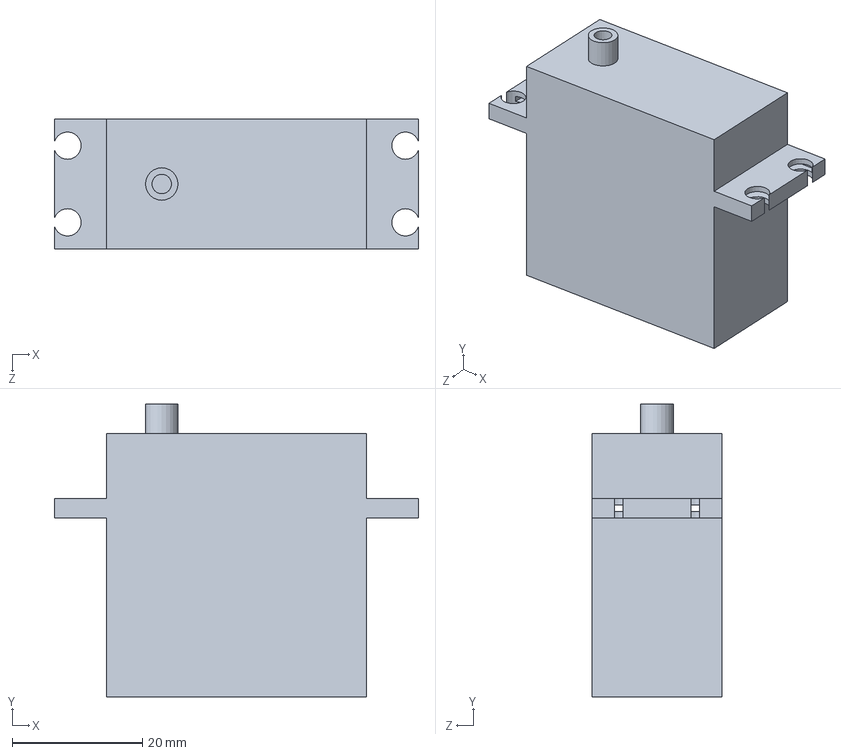
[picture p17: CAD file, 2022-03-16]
Documents/3D Printed Hardware Part Designs/20 kg servo.SLDPRT
56.0 x 45.0 x 20.0 mm

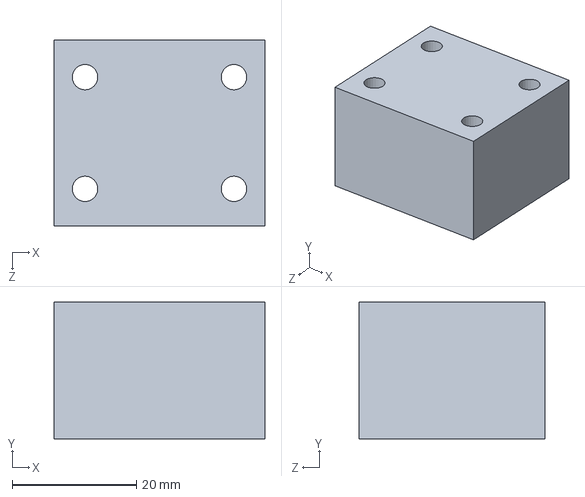
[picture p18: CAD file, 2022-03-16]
Documents/3D Printed Hardware Part Designs/Acrylic Carrier/scs 8 uu bearing.SLDPRT
34.0 x 22.0 x 30.0 mm

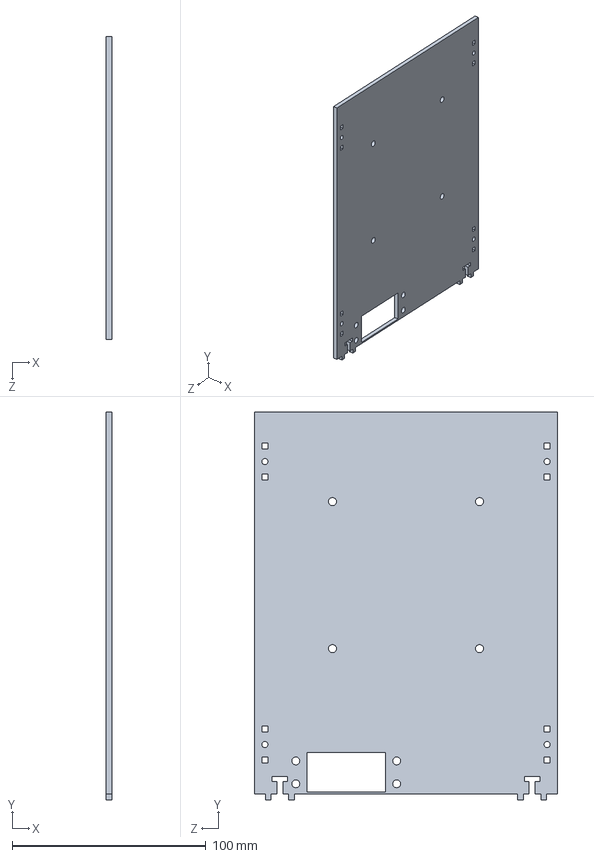
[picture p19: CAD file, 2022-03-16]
Documents/3D Printed Hardware Part Designs/Acrylic Carrier/capstone wall width with mounts for pi.SLDPRT
3.00 x 200.0 x 156.0 mm

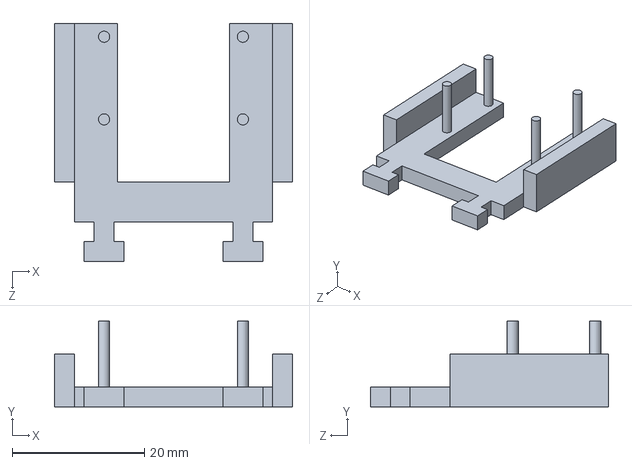
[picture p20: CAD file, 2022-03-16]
Documents/3D Printed Hardware Part Designs/pi camera mount 3.0.SLDPRT
36.0 x 13.0 x 36.0 mm

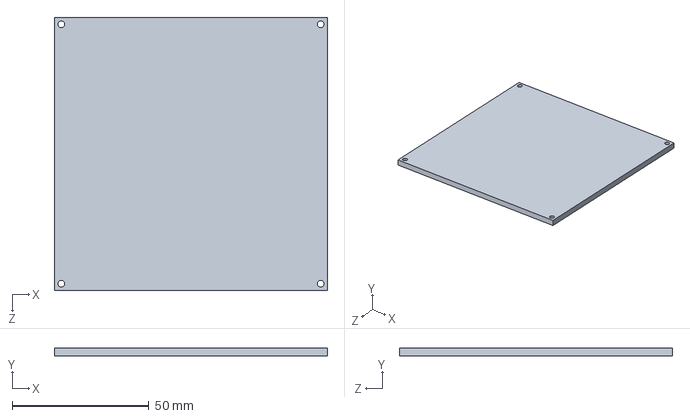
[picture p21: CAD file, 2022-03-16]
Documents/3D Printed Hardware Part Designs/Acrylic Carrier/false bottom.SLDPRT
100.0 x 3.00 x 100.0 mm

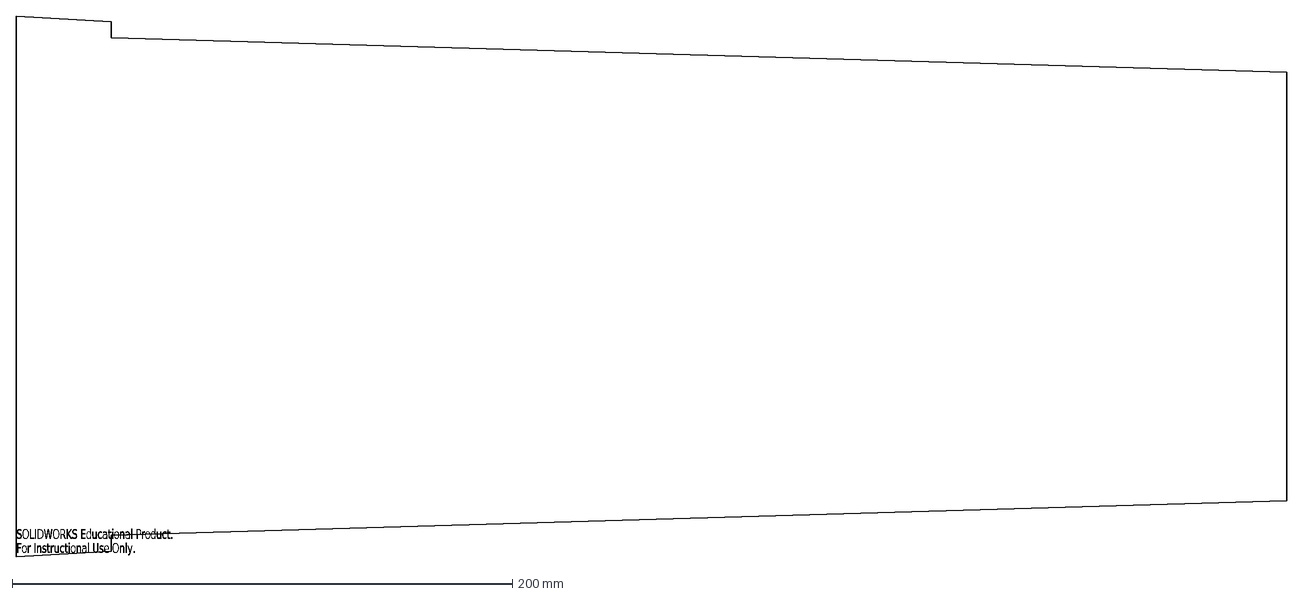
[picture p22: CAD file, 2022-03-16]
Documents/3D Printed Hardware Part Designs/divider 8.5.DXF
SOLIDWORKS Educational Product.
For Instructional Use Only.

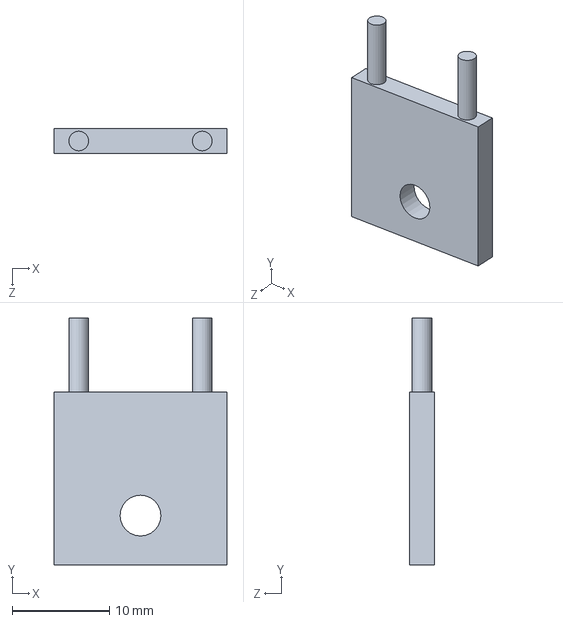
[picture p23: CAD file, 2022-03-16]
Documents/3D Printed Hardware Part Designs/voc mount.SLDPRT
17.8 x 25.4 x 2.54 mm

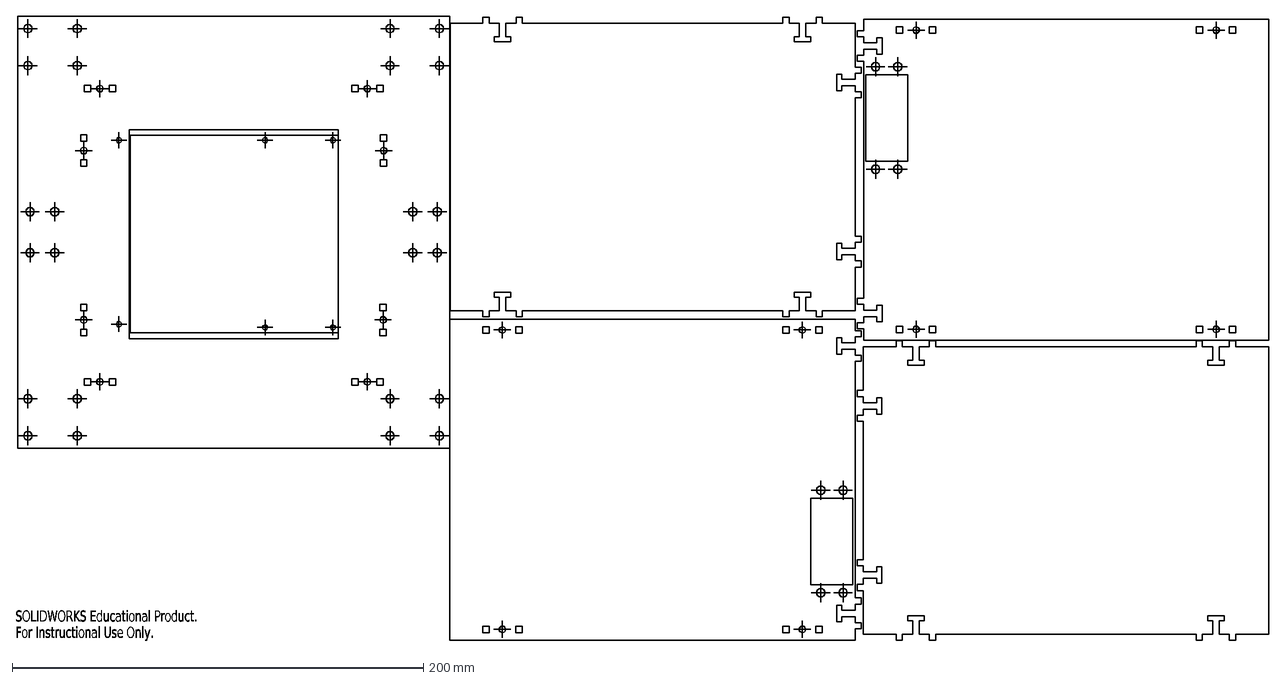
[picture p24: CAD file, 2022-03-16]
Documents/3D Printed Hardware Part Designs/Acrylic Carrier/sketch 4.5 i think.DXF
SOLIDWORKS Educational Product.
For Instructional Use Only.

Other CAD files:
Documents/3D Printed Hardware Part Designs/pi camera mount top 3.0.SLDPRT
Documents/3D Printed Hardware Part Designs/Acrylic Carrier/sketch 3.6 i think.DXF
Documents/3D Printed Hardware Part Designs/divider.SLDPRT
Documents/3D Printed Hardware Part Designs/8 mm bearing.SLDPRT
Documents/3D Printed Hardware Part Designs/Acrylic Carrier/capstone wall length.SLDPRT
Documents/3D Printed Hardware Part Designs/Acrylic Carrier/capstone wall width 3.0.DXF
Documents/3D Printed Hardware Part Designs/Acrylic Carrier/capstone wall width 3.5.DXF
Documents/3D Printed Hardware Part Designs/Acrylic Carrier/capstone wall width with mounts for pi.DXF
Documents/3D Printed Hardware Part Designs/Acrylic Carrier/capstone wall width.DXF
Documents/3D Printed Hardware Part Designs/Acrylic Carrier/capstone wall width.SLDPRT
Documents/3D Printed Hardware Part Designs/Acrylic Carrier/cheap servo.SLDPRT
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

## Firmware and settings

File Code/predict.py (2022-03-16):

import json, os, re, sys
import numpy as np
from keras import backend as K
from keras.models import load_model
from keras.preprocessing import image
from picamera import PiCamera
from time import sleep
from PIL import Image
import serial
import board
import busio
import adafruit_sgp30
import time

#Initiate weight sensor
EMULATE_HX711=False
if not EMULATE_HX711:
    import RPi.GPIO as GPIO
    from hx711 import HX711
else:
    from emulated_hx711 import HX711

def cleanAndExit():
    print ("Cleaning...")

    if not EMULATE_HX711:
        GPIO.cleanup()

    print ("Bye!")
    sys.exit()

hx = HX711(5, 6)

if __name__ == '__main__':
    model_path = sys.argv[1]

    print ('Loading serial')
    for x in range(10):
        name = '/dev/ttyACM' + str(x)
        try:
            ser = serial.Serial(name)
        except:
            continue

    print(ser.name)

    print('Loading model:', model_path)
    model = load_model(model_path)
    image2 = 'image2.jpg'
    run= 'y'


    voc = True
    weight_sensor = True

    # Setup i2c
    print('Setting up i2c...')
    try:
        thres_smell = 0
        min_smell = 0
        max_smell = 0
        smell = []
        i2c = busio.I2C(board.SCL, board.SDA, frequency=100000)
        sgp30 = adafruit_sgp30.Adafruit_SGP30(i2c)
        sgp30.iaq_init()
        sgp30.set_iaq_baseline(0x8973, 0x8aae)
        for i in range(40):
            print("eCO2 = %d ppm \t TVOC = %d ppb" % (sgp30.eCO2, sgp30.TVOC))
            sleep(1)
    except:
        print ("VOC failed")
        voc = False

    # Setup weight sensor
    print('Setting up weight sensor...')
    try:
        hx.set_reading_format("MSB", "MSB")
        hx.set_reference_unit(4.09)
        hx.reset()
        hx.tare(50)
        offset_prev = hx.tare(50)
    except:
        print ("weight sensor failed")
        weight_sensor = False
    print ("Place object now...")

    while(run =='y'):
        thres_smell = 0
        camera = PiCamera()
        camera.start_preview()
        sleep(10)
        camera.capture(image2)
        camera.stop_preview()

        if voc:
            smell = []
            for i in range(20):
                eCO2 = sgp30.eCO2
                TVOC = sgp30.TVOC
                print("eCO2 = %d ppm \t TVOC = %d ppb" % (eCO2, TVOC))
                smell.append(TVOC)
                sleep(0.25)
            smell = np.array(smell)
            b = smell[::-1]
            max_smell = len(b) - np.argmax(b) - 1
            if (max_smell == 0 ):
                thres_smell = 0
                min_smell = max_smell
            else:
                min_smell = np.argmin(smell[0:max_smell])
                thres_smell = smell[max_smell] - smell[min_smell]
            print("max", smell[max_smell], "min", smell[min_smell])

        imageCrop = Image.open(image2)
        cropped = imageCrop.crop((570,105,1365,830))
        save = cropped.save('imageC.jpg')
        img2 = image.load_img('imageC.jpg', target_size=(224, 224))
        y = image.img_to_array(img2)

        hx.set_offset_A(offset_prev)
        y = np.expand_dims(y, axis=0)
        preds = model.predict(y)
        print(preds)
        print('Generating predictions on image:', image2)

        category = 4
        for p in range(4):
            if (preds[0][p] >= 0.60):
                category = p


        target_names = [b'glass\n',b'metal\n',b'paper\n',b'plastic\n',b'trash\n']
        print('Predicted Category: ')
        print(target_names[category])
        print('After VOC test')
        if (thres_smell >= 20) and voc:
                category = 4
                print('VOC smelled food')
        print(target_names[category])

        weight = np.zeros(10)
        for w in range(10):
            weight[w] = hx.get_weight(1)
        med_weight = np.median(weight)
        print("Weight (in grams) =", med_weight)
        if (category == 1 or category == 3):
            print('After food weight test')
            if (med_weight >= 200) and weight_sensor:
                    category = 4
        print(target_names[category])
        ser.write(target_names[category])


        run = input('would you like to continue? y/n')
        camera.close()
        offset_prev = hx.tare(50)
        sleep(5)
    ser.close()

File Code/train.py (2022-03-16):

import math, json, os, sys

import keras
from keras.callbacks import EarlyStopping, ModelCheckpoint
from keras.layers import Dense, AveragePooling2D
from keras.layers import Flatten
from keras.models import Model
from keras.optimizers import Adam
from keras.preprocessing import image
import numpy as np
import sys
import scipy
from scipy import signal
from keras.applications.resnet50 import ResNet50
from keras.preprocessing import image
from keras.applications.resnet50 import preprocess_input, decode_predictions
from sklearn.metrics import confusion_matrix
from sklearn.metrics import accuracy_score
from sklearn.metrics import precision_score
from sklearn.metrics import recall_score
from sklearn.metrics import f1_score
import matplotlib.pyplot as plt
import warnings



DATA_DIR = 'data'
TRAIN_DIR = os.path.join(DATA_DIR, 'train')
VALID_DIR = os.path.join(DATA_DIR, 'valid')
SIZE = (224, 224)
BATCH_SIZE = 16

if __name__ == "__main__":

    num_train_samples = sum([len(files) for r, d, files in os.walk(TRAIN_DIR)])
    num_valid_samples = sum([len(files) for r, d, files in os.walk(VALID_DIR)])

    num_train_steps = math.floor(num_train_samples/BATCH_SIZE)
    num_valid_steps = math.floor(num_valid_samples/BATCH_SIZE)

    gen = keras.preprocessing.image.ImageDataGenerator(rotation_range = 45, horizontal_flip=True, vertical_flip=True)
    val_gen = keras.preprocessing.image.ImageDataGenerator(horizontal_flip=True, vertical_flip=True)

    batches = gen.flow_from_directory(TRAIN_DIR, target_size=SIZE, class_mode='categorical', shuffle=True, batch_size=BATCH_SIZE)
    val_batches = val_gen.flow_from_directory(VALID_DIR, target_size=SIZE, class_mode='categorical', shuffle=True, batch_size=BATCH_SIZE)
    input_size = 224
    input_channels= 3



    classes = list(iter(batches.class_indices))
    base_model = ResNet50(include_top = False,weights="imagenet",input_shape=(input_size,input_size,input_channels))
    x = AveragePooling2D((7,7),name='avg_pool')(base_model.output)
    x = Flatten()(x)
    x = Dense(len(classes),activation="softmax")(x)
    finetuned_model = Model(base_model.input,x)
    for layer in base_model.layers:
    	layer.trainable = False
    finetuned_model.save_weights("all_nontrainable50.h5")

    base_model = ResNet50(include_top = False,weights="imagenet",input_shape=(input_size,input_size,input_channels))
    x = AveragePooling2D((7,7),name='avg_pool')(base_model.output)
    x = Flatten()(x)
    x = Dense(len(classes),activation="softmax")(x)


    finetuned_model = Model(base_model.input,x)

    for layer in base_model.layers[:10]:
    	layer.trainable = False
    finetuned_model.load_weights("all_nontrainable50.h5")

    finetuned_model.compile(optimizer=Adam(lr=0.001), loss='categorical_crossentropy', metrics=['accuracy'])
    for c in batches.class_indices:
        classes[batches.class_indices[c]] = c
    finetuned_model.classes = classes

    early_stopping = EarlyStopping(monitor='val_loss',patience=10)
    checkpointer = ModelCheckpoint('resnet50_best_train_epoch_30.h5', verbose=1, save_best_only=True)

    history = finetuned_model.fit_generator(batches, steps_per_epoch=num_train_steps, epochs=30, callbacks=[early_stopping, checkpointer], validation_data=val_batches, validation_steps=num_valid_steps)
    finetuned_model.save('resnet50_train_epoch_30.h5')
    acc = history.history['acc']
    val_acc = history.history['val_acc']
    loss = history.history['loss']
    val_loss = history.history['val_loss']
    print(acc)
    print(loss)
    print(val_acc)
    print(val_loss)
    ep = range(len(acc))
    plt.plot(ep, val_loss,'b',label = 'Valid loss')
    plt.plot(ep,loss,'r',label='Training loss')
    plt.plot('T and V Loss')
    plt.legend()
    plt.show()
